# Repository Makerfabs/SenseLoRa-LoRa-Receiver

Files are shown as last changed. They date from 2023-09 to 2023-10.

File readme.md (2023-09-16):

# SENSELORA LORA RECEIVER

```c++
/*
Version:		V1.0
Author:			Vincent
Create Date:	2023/9/16
Note:

*/
```
# Makerfabs

[Makerfabs home page](https://www.makerfabs.com/)

[Makerfabs Wiki](https://wiki.makerfabs.com/)

# How To Use

## Arduino Complier Option

**If you have any questions，such as how to install the development board, how to download the code, how to install the library. Please refer to :[Makerfabs_FAQ](https://github.com/Makerfabs/Makerfabs_FAQ)**

- Please disconnect from the electrical equipment before burning!
- Do not burn with alternating current!
- Open Arduino IDE
- Open boards Manager, search "RP2040"
- Install board:  Arduino Mbed OS RP2040 Boards(Version 4.0.4)

Arduino libraries:

- RP2040_SD 1.0.1  
- RadioLib 4.6.0  
- Adafruit_GFX_Library 1.11.5  
- Adafruit_BusIO 1.14.1  
- Adafruit_SSD1306 2.5.1  

## Data Analysis

Once the device is plugged in, run data_analysis.py and the serial port will be found automatically. In addition, the json data uploaded by the device is classified according to ID and stored into different CSV files.

Make sure that no other serial device is connected, or modify the Python program yourself.

Environment:

- Python      3.11.2
- pyserial    3.5

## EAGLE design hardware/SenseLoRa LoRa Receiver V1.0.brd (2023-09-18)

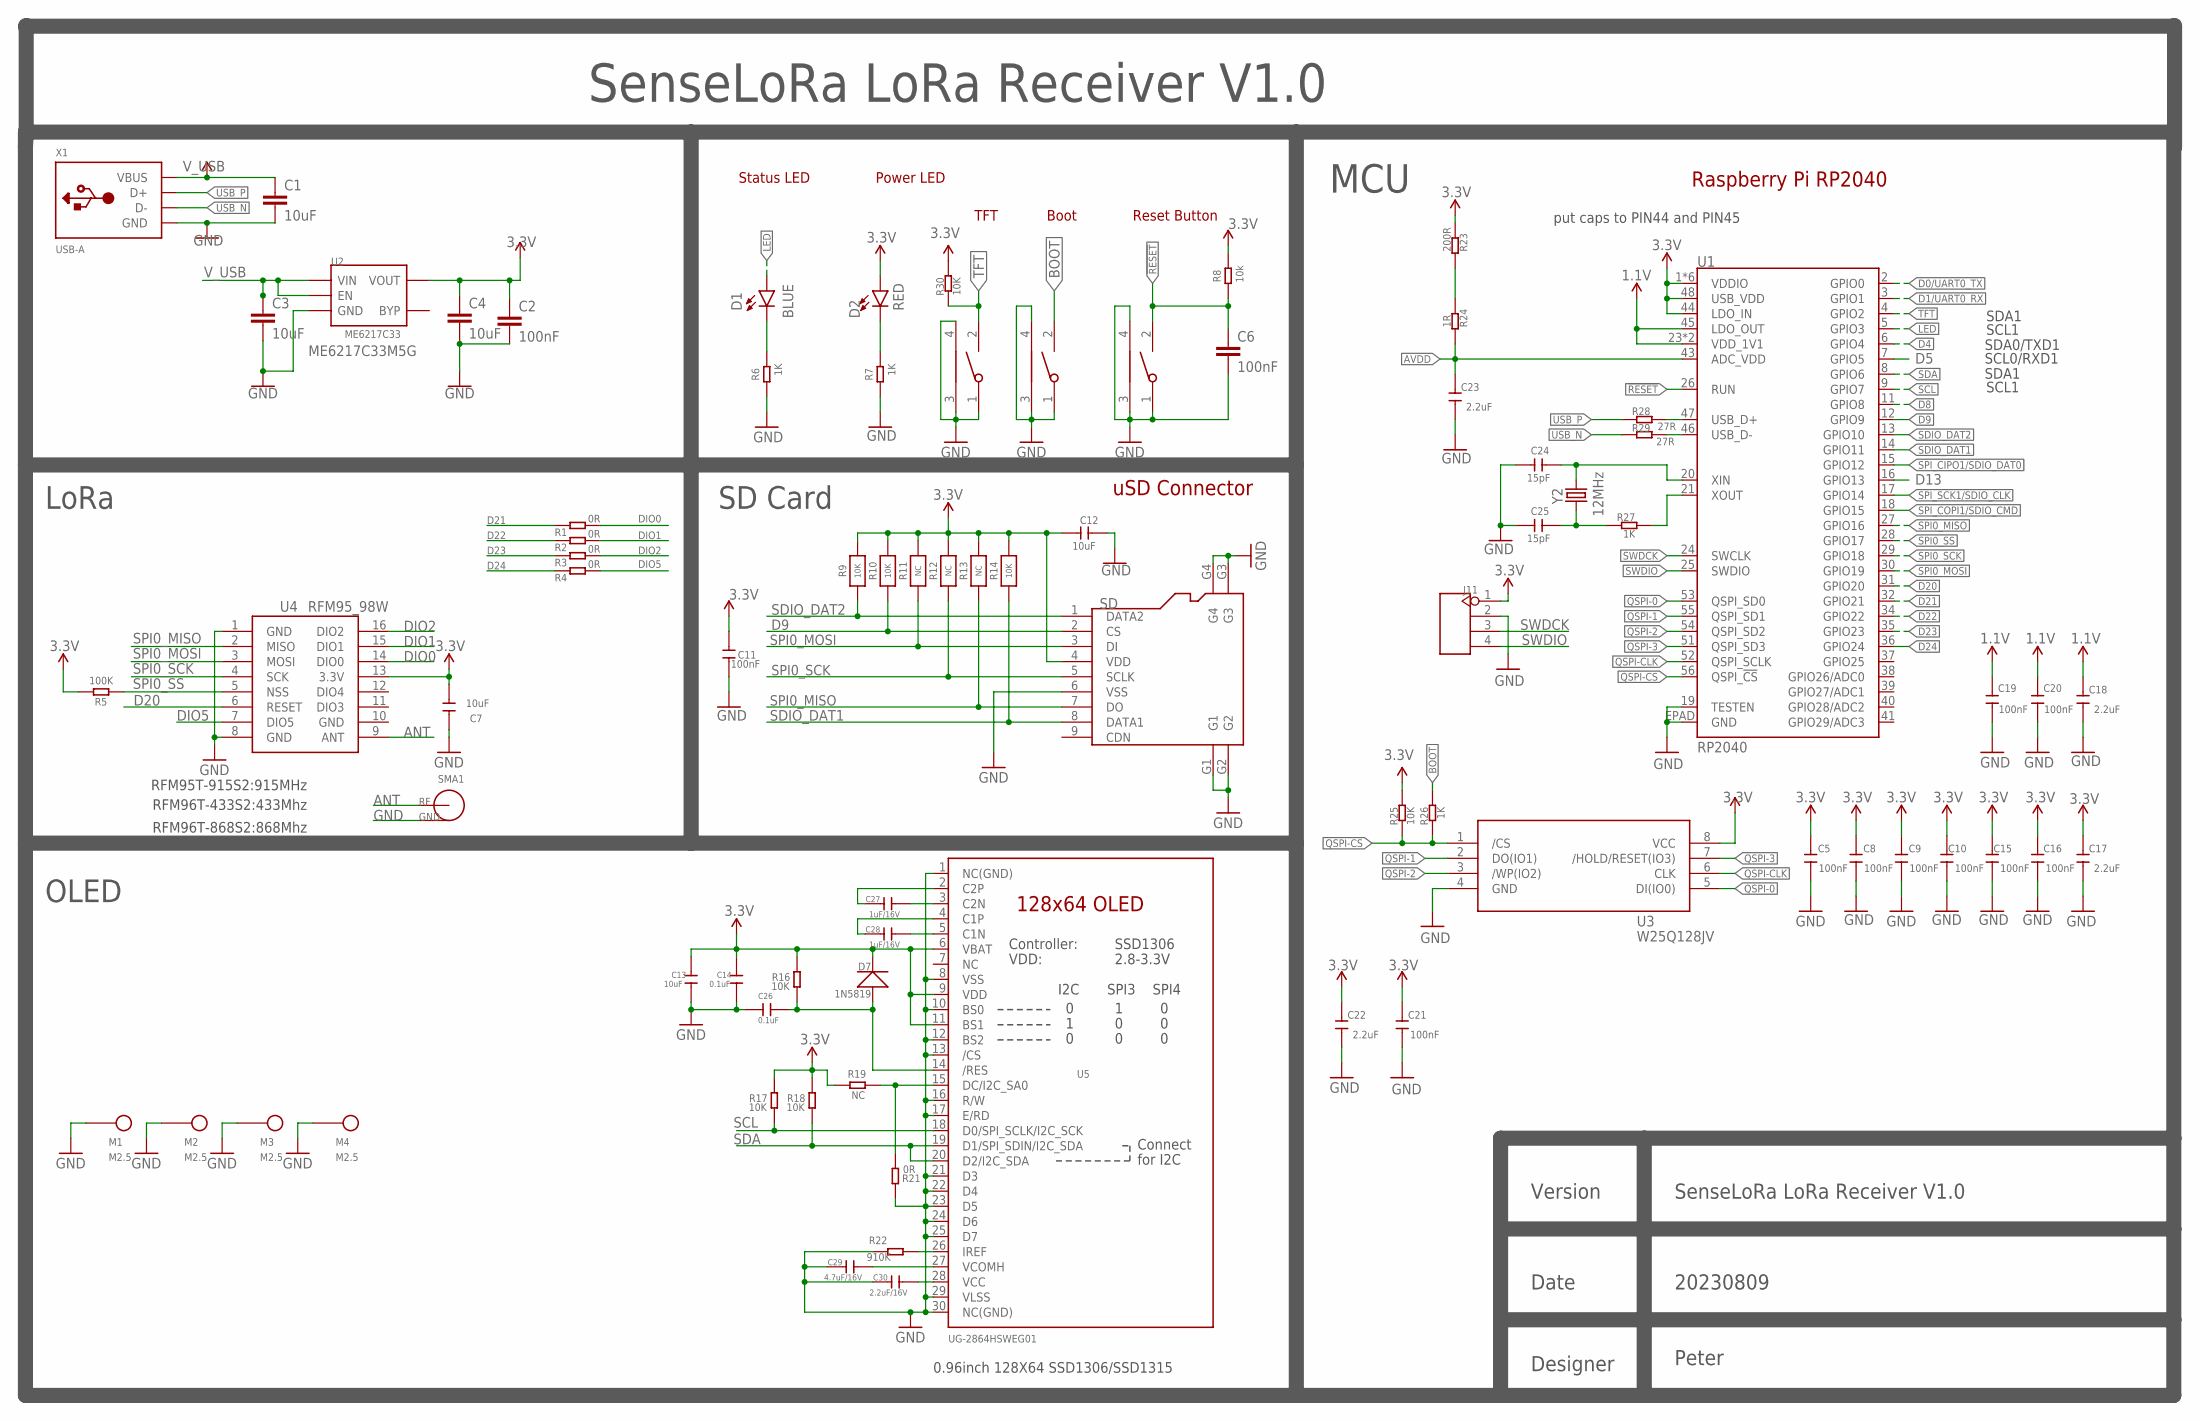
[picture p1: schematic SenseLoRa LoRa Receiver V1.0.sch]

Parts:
BOOT: TS24CA; 2*4*3.5MM
C1, C3, C4, C7, C13: 10uF; C0603
C2, C5, C6, C8, C9, C10, C11, C15, C16, C19, C20, C21: 100nF; C0603
C12: 10uF; DISCRETE_C0603
C14, C26: 0.1uF; C0603
C17, C18, C22, C23: 2.2uF; C0603
C24, C25: 15pF; C0603
C27, C28: 1uF/16V; C0603
C29: 4.7uF/16V; C0603
C30: 2.2uF/16V; C0603
D1: BLUE; LED-0603
D2: RED; LED-0603
D7: 1N5819; SOD323
J11: HEADER-4P-60/35MILROUND; 4P-65/35ROUND
M1, M2, M3, M4: M2.5
R1, R2, R3, R4, R21: 0R; 0603
R5: 100K; 0603
R6, R7, R26, R27: 1K; 0603
R8: 10k; 0603
R9, R10, R14: 10K; 0603-NO
R11, R12, R13: NC; 0603-NO
R16, R17, R18, R25, R30: 10K; 0603
R19: NC; 0603
R22: 910K; 0603
R23: 200R; 0603
R24: 1R; 0603
R28, R29: 27R; 0603
RST: TS24CA; 2*4*3.5MM
SD: HOLDER-MICROSD-9P; 9P-SMD-W/-RING
SMA1: SMA-KWE
TFT: TS24CA; 2*4*3.5MM
U1: RP2040; QFN-56
U2: ME6217C33; SOT23-5
U3: W25Q128JV; SOIC-8-208MIL
U4: RFM95_98W; RFM92_93W
U5: UG-2864HSWEG01; UG-2864HSWEG01_0.96IN_WRAPAROUND
X1: USB-A; MOLEX_480371000
Y2: 12MHz; CRYSTAL-SMD-2X2.5MM

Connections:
1.1V: C18.2, C19.2, C20.2, U1.23 (VDD_1V1), U1.45 (LDO_OUT), U1.50 (VDD_1V1)
3.3V: C2.1, C4.1, C5.2, C7.2, C8.2, C9.2, C10.2, C11.2, C12.2, C13.1, C14.1, C15.2, C16.2, C17.2, C21.2, C22.2, D2.A, D7.-, J11.1, R5.2, R8.1, R9.2, R10.2, R11.2, R12.2, R13.2, R14.2, R16.2, R17.2, R18.2, R19.2, R23.2, R25.1, R30.1, SD.4 (VDD), U1.1 (VDDIO), U1.10 (VDDIO), U1.22 (VDDIO), U1.33 (VDDIO), U1.42 (VDDIO), U1.44 (LDO_IN), U1.48 (USB_VDD), U1.49 (VDDIO), U2.5 (VOUT), U3.8 (VCC), U4.13 (3.3V), U5.6 (VBAT), U5.9 (VDD), U5.11 (BS1)
!RESET!: C6.1, R8.2, RST.2, U1.26 (RUN)
ADC_VREF: R23.1, R24.2
ANT: SMA1.1 (SIG), U4.9 (ANT)
AVDD: C23.2, R24.1, U1.43 (ADC_VDD)
BOOT: BOOT.2, R26.1
D0/UART0_TX: U1.2 (GPIO0)
D1/UART0_RX: U1.3 (GPIO1)
D4: U1.6 (GPIO4)
D5: U1.7 (GPIO5)
D8: U1.11 (GPIO8)
D9: R10.1, SD.2 (CS), U1.12 (GPIO9)
D13: U1.16 (GPIO13)
D20: U1.31 (GPIO20), U4.6 (RESET)
D21: R1.2, U1.32 (GPIO21)
D22: R2.2, U1.34 (GPIO22)
D23: R3.2, U1.35 (GPIO23)
D24: R4.2, U1.36 (GPIO24)
DIO0: R1.1, U4.14 (DIO0)
DIO1: R2.1, U4.15 (DIO1)
DIO2: R3.1, U4.16 (DIO2)
DIO5: R4.1, U4.7 (DIO5)
GND: BOOT.1, BOOT.3, BOOT.4, C1.2, C2.2, C3.2, C4.2, C5.1, C6.2, C7.1, C8.1, C9.1, C10.1, C11.1, C12.1, C13.2, C14.2, C15.1, C16.1, C17.1, C18.1, C19.1, C20.1, C21.1, C22.1, C23.1, C24.2, C25.2, C26.1, C29.1, C30.1, J11.2, M1.1, M2.1, M3.1, M4.1, R6.2, R7.2, R21.2, R22.2, RST.1, RST.3, RST.4, SD.6 (VSS), SD.G1, SD.G2, SD.G3, SD.G4, SMA1.2 (GND), SMA1.3 (GND), SMA1.4 (GND), SMA1.5 (GND), TFT.1, TFT.3, TFT.4, U1.19 (TESTEN), U1.EPAD (GND), U2.2 (GND), U3.4 (GND), U4.1 (GND), U4.8 (GND), U4.10 (GND), U5.1 (NC(GND)), U5.8 (VSS), U5.10 (BS0), U5.12 (BS2), U5.13 (/CS), U5.16 (R/W), U5.17 (E/RD), U5.21 (D3), U5.22 (D4), U5.23 (D5), U5.24 (D6), U5.25 (D7), U5.29 (VLSS), U5.30 (NC(GND)), X1.4 (GND)
LED: D1.A, U1.5 (GPIO3)
unnamed: C24.1, U1.20 (XIN), Y2.P3 (2)
unnamed: D1.C, R6.1
unnamed: R19.1, R21.1, U5.15 (DC/I2C_SA0)
unnamed: R27.1, U1.21 (XOUT)
unnamed: C29.2, U5.27 (VCOMH)
unnamed: C25.1, R27.2, Y2.P1 (1)
unnamed: D2.C, R7.1
unnamed: C30.2, U5.28 (VCC)
unnamed: R22.1, U5.26 (IREF)
unnamed: C27.2, U5.3 (C2N)
unnamed: C27.1, U5.2 (C2P)
unnamed: C28.1, U5.4 (C1P)
unnamed: C28.2, U5.5 (C1N)
unnamed: C26.2, D7.+, R16.1, U5.14 (/RES)
QSPI-0: U1.53 (QSPI_SD0), U3.5 (DI(IO0))
QSPI-1: U1.55 (QSPI_SD1), U3.2 (DO(IO1))
QSPI-2: U1.54 (QSPI_SD2), U3.3 (/WP(IO2))
QSPI-3: U1.51 (QSPI_SD3), U3.7 (/HOLD/RESET(IO3))
QSPI-CLK: U1.52 (QSPI_SCLK), U3.6 (CLK)
QSPI-CS: R25.2, R26.2, U1.56 (QSPI_!CS!), U3.1 (/CS)
SCL: R17.1, U1.9 (GPIO7), U5.18 (D0/SPI_SCLK/I2C_SCK)
SDA: R18.1, U1.8 (GPIO6), U5.19 (D1/SPI_SDIN/I2C_SDA), U5.20 (D2/I2C_SDA)
SDIO_DAT1: R14.1, SD.8 (DATA1), U1.14 (GPIO11)
SDIO_DAT2: R9.1, SD.1 (DATA2), U1.13 (GPIO10)
SPI0_MISO: R13.1, SD.7 (DO), U1.27 (GPIO16), U4.2 (MISO)
SPI0_MOSI: R11.1, SD.3 (DI), U1.30 (GPIO19), U4.3 (MOSI)
SPI0_SCK: R12.1, SD.5 (SCLK), U1.29 (GPIO18), U4.4 (SCK)
SPI0_SS: R5.1, U1.28 (GPIO17), U4.5 (NSS)
SPI_CIPO1/SDIO_DAT0: U1.15 (GPIO12)
SPI_COPI1/SDIO_CMD: U1.18 (GPIO15)
SPI_SCK1/SDIO_CLK: U1.17 (GPIO14)
SWDCK: J11.3, U1.24 (SWCLK)
SWDIO: J11.4, U1.25 (SWDIO)
TFT: R30.2, TFT.2, U1.4 (GPIO2)
USB_F_N: R29.1, U1.46 (USB_D-)
USB_F_P: R28.1, U1.47 (USB_D+)
USB_N: R29.2, X1.2 (D-)
USB_P: R28.2, X1.3 (D+)
V_USB: C1.1, C3.1, U2.1 (VIN), U2.3 (EN), X1.1 (VBUS)

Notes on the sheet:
RFM95T-915S2:915MHz
RFM96T-433S2:433Mhz
uSD Connector
Raspberry Pi RP2040
Reset Button
Status LED
Boot
Power LED
put caps to PIN44 and PIN45
SDA0/TXD1
SCL0/RXD1
SDA1
SCL1
RFM96T-868S2:868Mhz
LoRa
MCU
SenseLoRa LoRa Receiver V1.0
Version
Date
Designer
20230809
Peter
ME6217C33M5G
SD Card
0.96inch 128X64 SSD1306/SSD1315
OLED
TFT

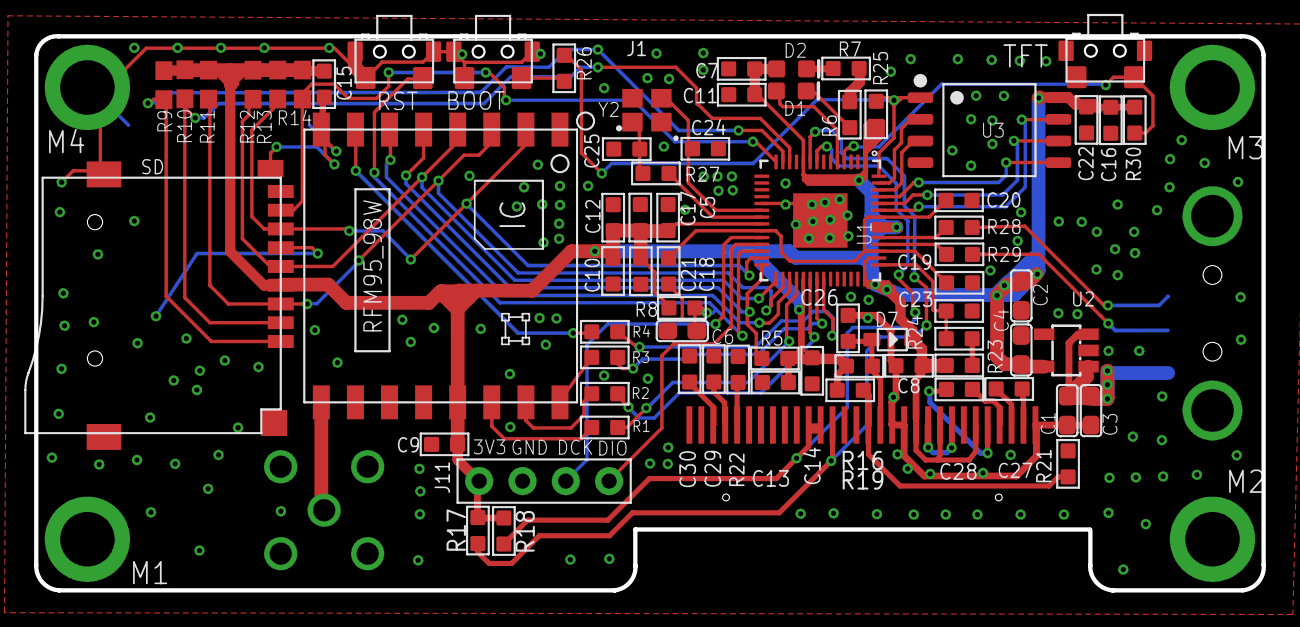
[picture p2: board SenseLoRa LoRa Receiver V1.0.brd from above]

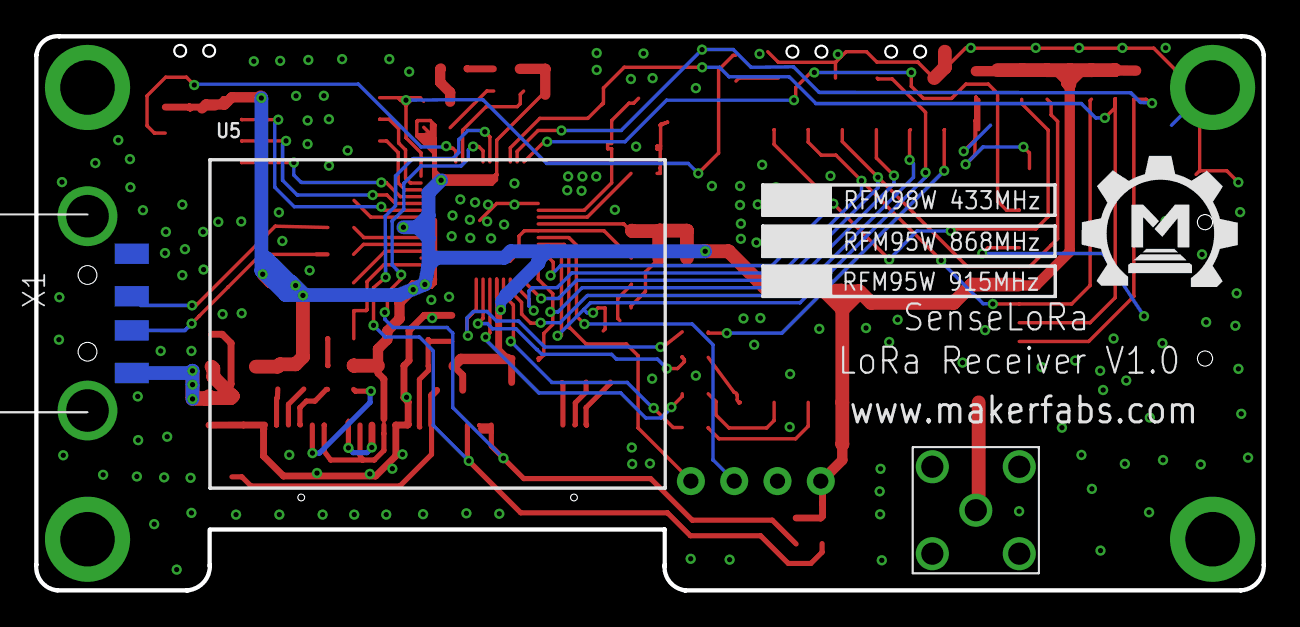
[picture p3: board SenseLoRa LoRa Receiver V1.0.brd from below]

Board: 2 copper layers, 72.0 x 32.5 mm, 79 parts (4 on the bottom side), 55 nets.

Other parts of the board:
U$1: MAKERFABS_0.3

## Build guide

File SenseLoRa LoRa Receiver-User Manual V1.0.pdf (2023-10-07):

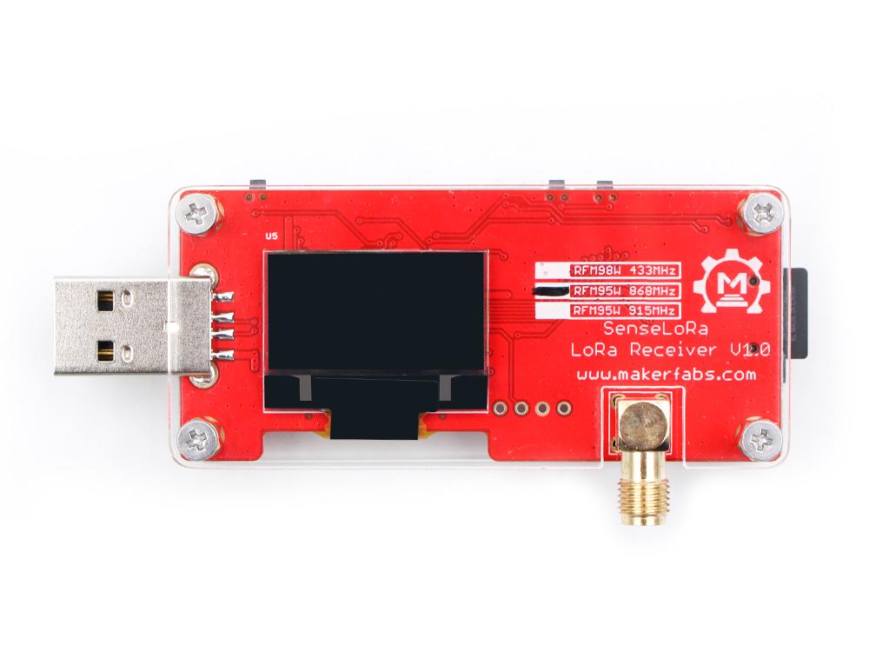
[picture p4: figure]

1 / 8

# SenseLoRa LoRa Receiver

### Version： V1.0

### Data： 2023-09-26

### Author： Peter

2 / 8

## Contents

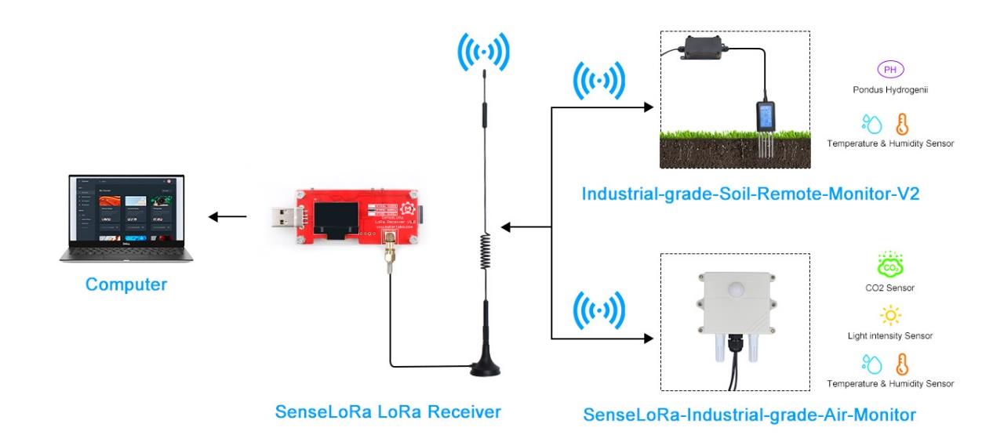
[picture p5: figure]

3 / 8

# 1. Introduction

### 1.1 Function

LoRa Receiver is a data receiver based on LoRa P2P protocol. It can receive

data sent by multiple sensor products around and forward to computer so the

data can be displayed/recorded and analysis via the PC.

LoRa Receiver is connected to the computer via USB. The received real-

time data can be displayed real time on the PC , and also on the screen of the

product, while the backup is saved to the SD card.

User can also view the sensor data received through the serial port of the

computer, and can also analyze the data saved in EXCEL.

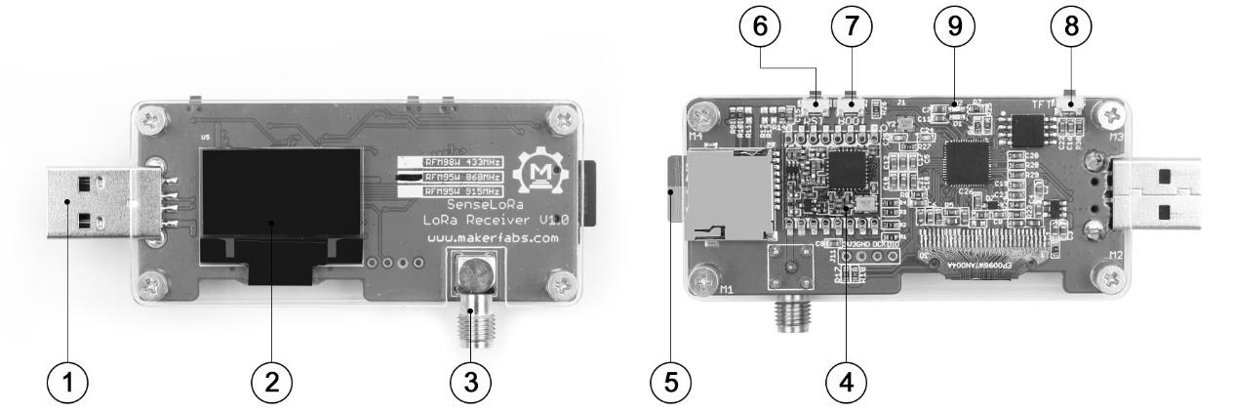
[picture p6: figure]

4 / 8

### 1.2 General description

① USB-A interface

② Display

③ Antenna

④ LoRa

⑤ SD card

⑥ Reset button

⑦ Burn button

⑧ Display rotation button

⑨ Power LED

# 2. Installation

### 2.1 Part List

Description | Specification | PCS
Receiver | 88mm*34mm*18mm | 1
Antenna | 5000mm | 1
Micro SD card | 16GB | 1

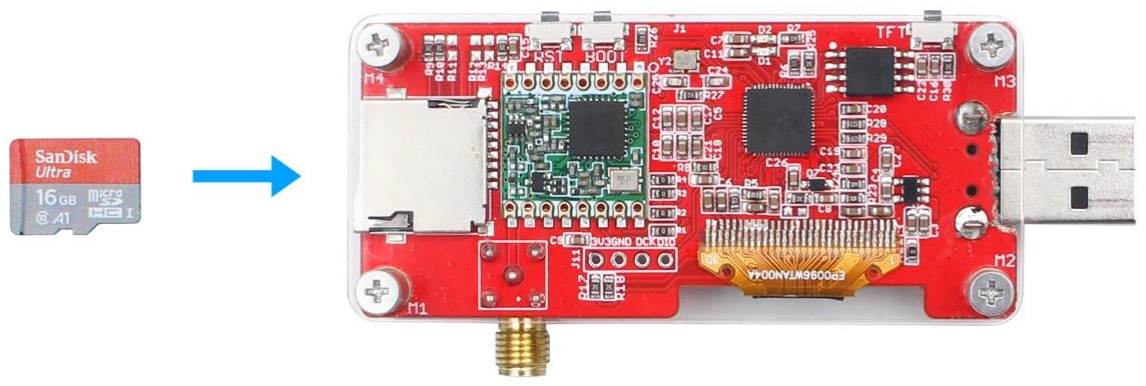
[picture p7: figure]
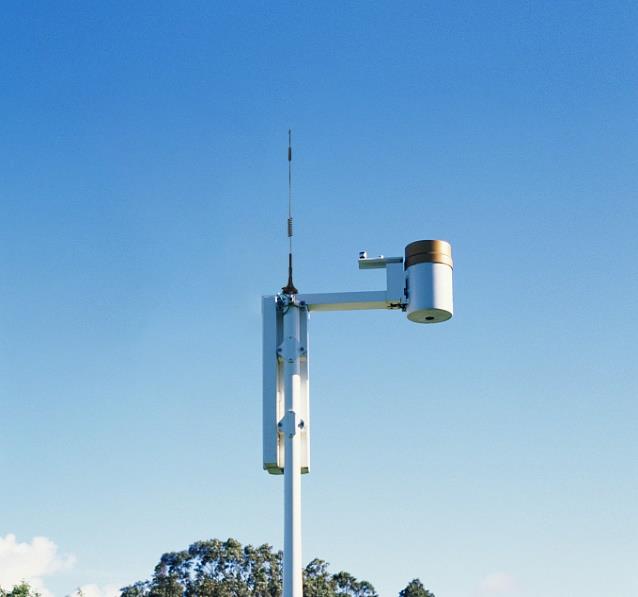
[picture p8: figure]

5 / 8

### 2.2 SD card Installation

Take out the SD card and place it in the SD card slot.

### 2.3 Antenna Installation

The antenna is 5m long, can be installed outside, to ensure the best LoRa

communication range.

Working with Makerfabs SenseLoRa nodes, the LoRa communication arrange

can be up to 4~5 KM.

### 2.4 Power Supply

The product connects to the computer via USB to work.

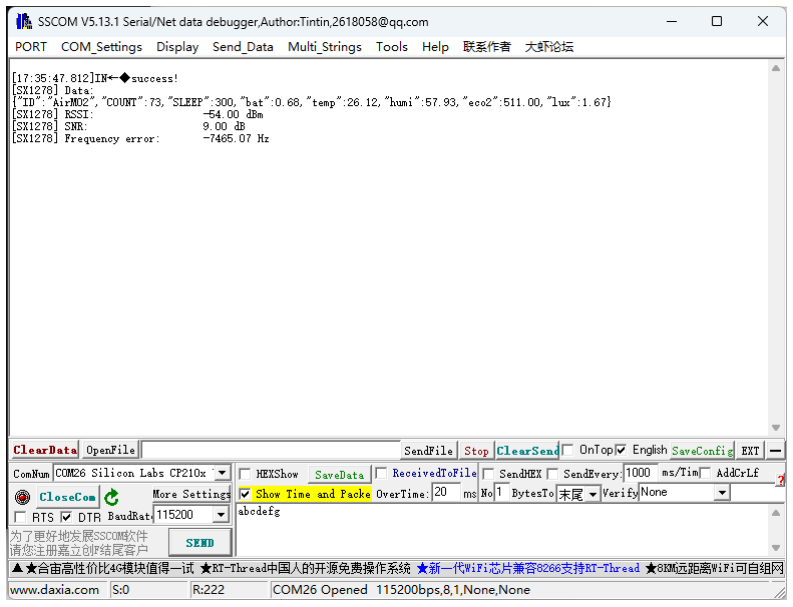
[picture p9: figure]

6 / 8

## 3. Data Management

The product is installed and receives sensor data. Users can save and

process data in several ways.

### 3.1 Serial port

Open the serial port tool on the PC, the parameters are set as follows：

Baud rate : 115200

Data bits : 8

Stop bits : 1

Parity :None

Flow control : None

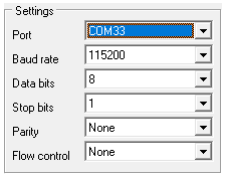
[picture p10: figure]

Select the product port and open it, the received sensor data will be

displayed in real time.

### 3.2 Python Application

The URL: https://github.com/Makerfabs/SenseLoRa-LoRa-Receiver/tree/main/data_analysis

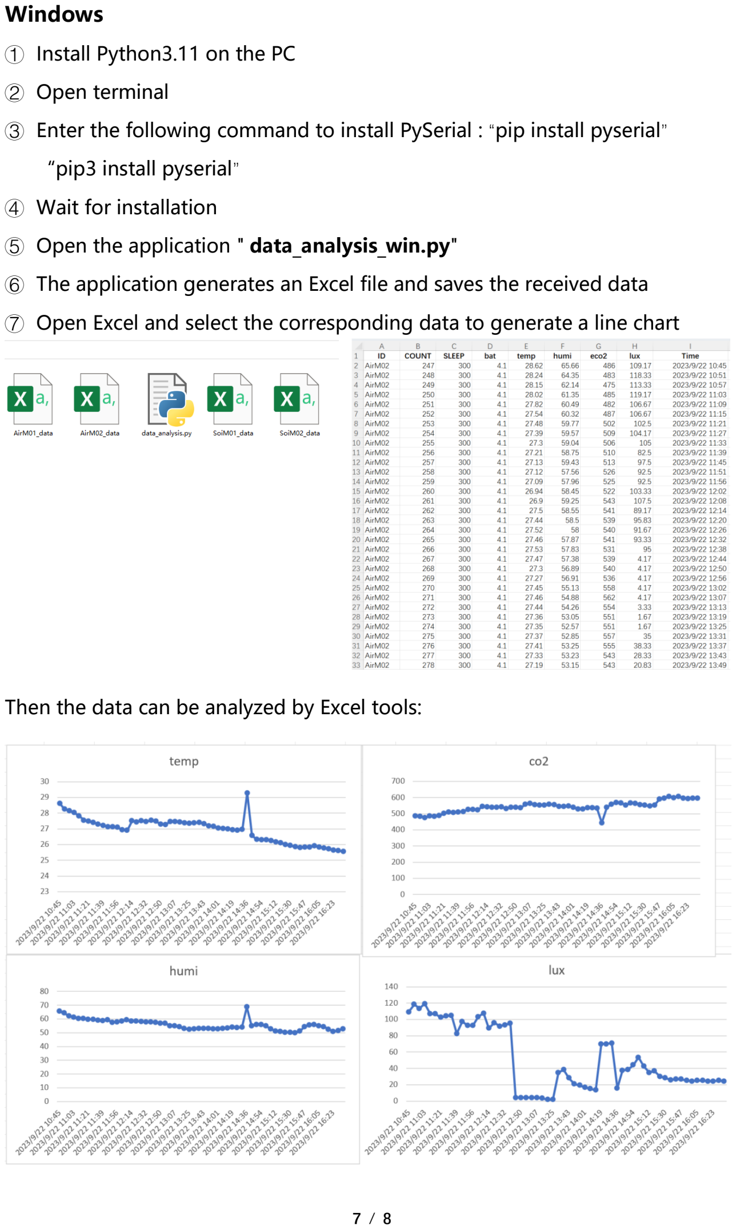
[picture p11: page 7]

7 / 8

### Windows

① Install Python3.11 on the PC

② Open terminal

③ Enter the following command to install PySerial : “pip install pyserial”

“pip3 install pyserial”

④ Wait for installation

⑤ Open the application " data_analysis_win.py"

⑥ The application generates an Excel file and saves the received data

⑦ Open Excel and select the corresponding data to generate a line chart

Then the data can be analyzed by Excel tools:

8 / 8

### Mac OS x

① Install Python3.11 on the PC

② Open terminal

③ Enter the following command to install PIP : “python -m ensurepip”

④ Enter the following command to install PySerial : “pip install pyserial” or

“pip3 install pyserial”

⑤ Wait for installation

⑥ Open the application " data_analysis_mac.py"

⑦ The application generates an Excel file and saves the received data

⑧ Data analysis as above

### 3.3 SD card

All LoRa data are also been stored in the SD card, can be a back up for

long time monitoring in application.

## 4. Specifications

Model | SenseLoRa LoRa Receiver
Power supply | 5V / 0.5W
Frequency Bands | EU868/ US915
Physical characteristics
Dimensions (height x width x Depth) | 88 x 34 x 18mm
Weight main unit | 65g
Antenna length | 5000mm

Operating conditions

Temperature -40°C to +80°C

Relative humidity 15% to 90% (no condensation) Storage conditions

Temperature -20°C to +50°C

Relative humidity 15% to 90% (no condensation)

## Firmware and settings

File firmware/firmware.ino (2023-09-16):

/*

Must change pins_arduino.h
File may in this place:
C:\Users\vincent\AppData\Local\Arduino15\packages\arduino\hardware\mbed_rp2040\4.0.4\variants\RASPBERRY_PI_PICO\pins_arduino.h

// Wire
// #define PIN_WIRE_SDA        (4u)
// #define PIN_WIRE_SCL        (5u)

// Change By Vincent
#define PIN_WIRE_SDA        (6u)
#define PIN_WIRE_SCL        (7u)

*/

// Arduino Mbed OS RP2040 Boards version 4.0.4
// 使用库 SPI 在文件夹： C:\Users\vincent\AppData\Local\Arduino15\packages\arduino\hardware\mbed_rp2040\4.0.4\libraries\SPI (legacy)
// 使用 1.0.1  版本的库 RP2040_SD 在文件夹： C:\Users\vincent\Documents\Arduino\libraries\RP2040_SD
// 使用 4.6.0  版本的库 RadioLib 在文件夹： C:\Users\vincent\Documents\Arduino\libraries\RadioLib
// 使用库 Wire 在文件夹： C:\Users\vincent\AppData\Local\Arduino15\packages\arduino\hardware\mbed_rp2040\4.0.4\libraries\Wire (legacy)
// 使用 1.11.5  版本的库 Adafruit_GFX_Library 在文件夹： C:\Users\vincent\Documents\Arduino\libraries\Adafruit_GFX_Library
// 使用 1.14.1  版本的库 Adafruit_BusIO 在文件夹： C:\Users\vincent\Documents\Arduino\libraries\Adafruit_BusIO
// 使用 2.5.1  版本的库 Adafruit_SSD1306 在文件夹： C:\Users\vincent\Documents\Arduino\libraries\Adafruit_SSD1306

#include "config.h"

Adafruit_SSD1306 display(SCREEN_WIDTH, SCREEN_HEIGHT, &Wire, -1);
SX1276 radio = new Module(LORA_CS, LORA_DIO0, LORA_RST, LORA_DIO1, SPI, SPISettings());
File root;
File myFile;
long unsigned int runtime = 0;
int count = 0;
int sd_flag = 0;
int screen_rotation = 2;
int button_flag = 0;

int last_rssi = 0;
String oled_str = "No Massage";
int flesh_flag = 0;

void setup(void)
{
    Serial.begin(115200);

    pinMode(LORA_CS, OUTPUT);
    pinMode(SD_CS, OUTPUT);

    pinMode(PIN_SPI_MISO, INPUT);
    pinMode(PIN_SPI_MOSI, OUTPUT);
    pinMode(PIN_SPI_SCK, OUTPUT);

    pinMode(BUTTON_PIN, INPUT_PULLUP);

    delay(2000);
    Serial.println(F("Hello! SenseLoRa LoRa Receiver"));

    oled_init();
    sd_flag = sd_init();
    lora_init();

    while (0)
    {
        lora_send_task("AAAA");
        delay(10000);
    }

    runtime = millis();
    attachInterrupt(BUTTON_PIN, button_func, FALLING); // CHANGE FALLING RISING
    flesh_flag = 1;
}

void loop()
{
    if (button_flag == 1)
    {
        if (screen_rotation == 2)
            screen_rotation = 0;
        else
            screen_rotation = 2;
        display.setRotation(screen_rotation);
        Serial.println("Rotation OLED");
        button_flag = 0;

        flesh_flag = 1;
    }

    if (flesh_flag == 1)
    {
        oled_display();
        flesh_flag = 0;
    }

    lora_node_general();
    if ((millis() - runtime) > 5000)
    {
        // record_msg("loop");
        // log_read();
        runtime = millis();
    }
}

void lora_init()
{
    SD_CS_OFF;
    LORA_CS_ON;

    int state = radio.begin(FREQUENCY, BANDWIDTH, SPREADING_FACTOR, CODING_RATE, SX127X_SYNC_WORD, OUTPUT_POWER, PREAMBLE_LEN, GAIN);

    if (state == ERR_NONE)
    {
        Serial.println(F("Lora init success!"));
    }
    else
    {
        Serial.print(F("Lora init failed, code "));
        Serial.println(state);
        while (true)
            ;
    }
}

void lora_node_general()
{
    // Serial.print(F("[SX1278] Waiting for incoming transmission ... "));

    String str;
    int state = radio.receive(str);

    if (state == ERR_NONE)
    {
        int rssi = radio.getRSSI();
        // // packet was successfully received
        // Serial.println(F("Get lora message!"));

        // // print the data of the packet
        // Serial.println(F("[SX1278] Data:\t\t\t"));
        Serial.println(str);

        // // print the RSSI (Received Signal Strength Indicator)
        // // of the last received packet
        // Serial.print(F("[SX1278] RSSI:\t\t\t"));
        // Serial.print(rssi);
        // Serial.println(F(" dBm"));

        // // print the SNR (Signal-to-Noise Ratio)
        // // of the last received packet
        // Serial.print(F("[SX1278] SNR:\t\t\t"));
        // Serial.print(radio.getSNR());
        // Serial.println(F(" dB"));

        // // print frequency error
        // // of the last received packet
        // Serial.print(F("[SX1278] Frequency error:\t"));
        // Serial.print(radio.getFrequencyError());
        // Serial.println(F(" Hz"));

        String temp = "";
        temp = temp + "Num:" + ++count;
        record_msg(temp);
        record_msg(str);

        oled_str = str;
        last_rssi = rssi;
        flesh_flag = 1;
    }
    else if (state == ERR_RX_TIMEOUT)
    {
        // timeout occurred while waiting for a packet
        // Serial.println(F("timeout!"));
    }
    else if (state == ERR_CRC_MISMATCH)
    {
        // packet was received, but is malformed
        Serial.println(F("CRC error!"));
    }
    else
    {
        // some other error occurred
        Serial.print(F("failed, code "));
        Serial.println(state);
    }
}

int sd_init()
{
    LORA_CS_OFF;
    SD_CS_ON;

    int fail_count = 0;

    while (1)
    {
        if (fail_count > 2)
            return 0;
        if (!SD.begin(SD_CS))
        {
            SD.end();
            Serial.println("SD init failed!");
            fail_count++;
            delay(500);
            continue;
        }
        else
        {
            Serial.println("SD init done.");
            record_msg("New Restart.......");
            return 1;
        }
    }
}

void record_msg(String data)
{
    if (!sd_flag)
        return;
    LORA_CS_OFF;
    SD_CS_ON;

    File myFile = SD.open(LOG_FILE, FILE_WRITE);

    myFile.println(data.c_str());
    myFile.close();

    SD_CS_OFF;
    LORA_CS_ON;
}

void log_read()
{
    if (!sd_flag)
        return;
    LORA_CS_OFF;
    SD_CS_ON;

    Serial.println("log_read()");

    File myFile = SD.open(LOG_FILE, FILE_READ);
    while (myFile.available())
    {
        Serial.write(myFile.read());
    }

    // close the file:
    myFile.close();

    SD_CS_OFF;
    LORA_CS_ON;
}

void oled_init()
{
    Wire.begin();
    Wire.setClock(100000UL);

    if (!display.begin(SSD1306_SWITCHCAPVCC, 0x3C))
    { // Address 0x3C for 128x32
        Serial.println(F("SSD1306 allocation failed"));
        for (;;)
            ; // Don't proceed, loop forever
    }
    Serial.println("SSD1306 found");

    display.setRotation(screen_rotation);
    display.clearDisplay();
    for (int16_t x = 0; x < display.width(); x += 1) // SCREEN_WIDTH
    {
        for (int16_t y = 0; y < display.height(); y += 1) //
        {
            display.drawPixel(x, y, SSD1306_WHITE);
        }
        delay(1);
    }
    display.display();

    delay(2000);

    display.clearDisplay();
    display.setTextColor(SSD1306_WHITE);
    display.setTextSize(2); // Draw 2X-scale text
    display.setCursor(0, 0);
    display.println("SenseLoRa");
    display.println("LoRa");
    display.println("Receiver");
    display.display();

    display.setTextSize(1);
}

void button_func()
{
    button_flag = 1;
}

//

void lora_send_task(String data)
{
    Serial.println(data);
    int state = radio.transmit(data.c_str());
    if (state == ERR_NONE)
    {
        // the packet was successfully transmitted
        Serial.println(F(" success!"));

        // print measured data rate
        Serial.print(F("[SX1276] Datarate:\t"));
        Serial.print(radio.getDataRate());
        Serial.println(F(" bps"));
    }
    else if (state == ERR_PACKET_TOO_LONG)
    {
        // the supplied packet was longer than 256 bytes
        Serial.println(F("too long!"));
    }
    else if (state == ERR_TX_TIMEOUT)
    {
        // timeout occurred while transmitting packet
        Serial.println(F("timeout!"));
    }
    else
    {
        // some other error occurred
        Serial.print(F("failed, code "));
        Serial.println(state);
    }
}

void oled_display()
{
    String temp = "";
    temp = temp + "Num:" + count;

    display.clearDisplay();
    display.setCursor(0, 0);
    display.print(temp);
    display.println((String) " | " + last_rssi + "dbm");
    display.println(oled_str);
    display.display();
}

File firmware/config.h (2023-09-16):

#include <SPI.h>
#include <RP2040_SD.h>
#include <RadioLib.h>
#include <Wire.h>
#include <Adafruit_GFX.h>
#include <Adafruit_SSD1306.h>
#include <arduino.h>

// Pin

#define BUTTON_PIN 2

#define I2C_SDA_PIN 6
#define I2C_SCL_PIN 7

#define PIN_SPI_MISO (16u)
#define PIN_SPI_MOSI (19u)
#define PIN_SPI_SCK (18u)
#define PIN_SPI_SS (17u)

#define LORA_DIO0 21
#define LORA_DIO1 22
#define LORA_DIO2 23
#define LORA_DIO5 24
#define LORA_RST 20

#define LORA_CS 17
#define SD_CS 9

#define LORA_CS_OFF digitalWrite(LORA_CS, HIGH)
#define LORA_CS_ON digitalWrite(LORA_CS, LOW)
#define SD_CS_OFF digitalWrite(SD_CS, HIGH)
#define SD_CS_ON digitalWrite(SD_CS, LOW)

// Oled
#define SCREEN_WIDTH 128 // OLED display width, in pixels
#define SCREEN_HEIGHT 64 // OLED display height, in pixels

// Lora
#define FREQUENCY 868.0
#define BANDWIDTH 125.0
#define SPREADING_FACTOR 12
#define CODING_RATE 6
#define OUTPUT_POWER 20
#define PREAMBLE_LEN 8
#define GAIN 0

// SD
#define LOG_FILE "Lora_Log.txt"

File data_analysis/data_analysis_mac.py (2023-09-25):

# coding=utf-8
import serial
import time
import json
import csv
import os
import serial.tools.list_ports


def main():

    time.sleep(5)
    ser.write("begin".encode('UTF-8'))

    while True:
        read_data()
    pass


# Get lora message!
# [SX1278] Data:			
# {"ID":"0xAAAA","SLEEP":10,"temp":0.00,"humi":0.00,"eco2":0.00,"lux":0.00}
# [SX1278] RSSI:			-55 dBm
# [SX1278] SNR:			9.75 dB
# [SX1278] Frequency error:	4744.54 Hz
# Get lora message!
# [SX1278] Data:			
# {"ID":"0xBBBB","SLEEP":10,"temp":0.00,"humi":0.00,"eco2":0.00,"lux":0.00}
# [SX1278] RSSI:			-41 dBm
# [SX1278] SNR:			9.50 dB
# [SX1278] Frequency error:	767.82 Hz
# Get lora message!
# [SX1278] Data:			
# {"ID":"0xAAAA","SLEEP":10,"temp":0.00,"humi":0.00,"eco2":0.00,"lux":0.00}
# [SX1278] RSSI:			-54 dBm
# [SX1278] SNR:			9.50 dB
# [SX1278] Frequency error:	4744.02 Hz


def read_data():

    ser.reset_input_buffer()
    line = ser.readline().decode('UTF-8').replace('\n', '')
    # line = ser.readline().decode('UTF-8')
    # print(line)

    try:
        data = json.loads(line)
        list_title = []
        list_value = []
        print(data)
        for key in data:
            # print(key, data[key])
            list_title.append(key)
            list_value.append(data[key])

        time_str = time.strftime("%Y-%m-%d %H:%M:%S ",
                                 time.localtime(time.time()))
        print(time_str)
        print(list_title)
        print(list_value)

        list_value.append(time_str)
        list_title.append("Time")

        if list_title[0] == "ID":
            save_data(list_title, list_value)

    except:
        print("LOG:", line)


def save_data(list_title, list_value):
    filename = str(list_value[0]) + "_data.csv"
    title_flag = 0

    # 判断文件是否存在
    if os.path.exists(filename):
        print('Old sensor')

    else:
        print('New sensor')
        title_flag = 1

    file = open(filename, mode='a', newline='')
    writer = csv.writer(file)
    if title_flag == 1:
        writer.writerow(list_title)
    writer.writerow(list_value)

    file.close()


def get_com_list():
    global port_list
    port_list = serial.tools.list_ports.comports()
    return port_list


def get_frist_com():
    if len(get_com_list()) <= 0:
        print("No COM")
        return ""
    else:
        print("First COM")
        port_list = get_com_list()
        for com in port_list:
            print(com)
            for i in com:
                print(i)
                if i == "RaspberryPi Pico":
                    return list(com)[0]
            
        return NULL

# print("Input Serial number, don't add COM, just number.")
# serial_num = input()
# serial_num = "COM" + str(serial_num)
# ser = serial.Serial(serial_num, 115200)


ser = serial.Serial(get_frist_com(), 115200)

if __name__ == '__main__':
    main()

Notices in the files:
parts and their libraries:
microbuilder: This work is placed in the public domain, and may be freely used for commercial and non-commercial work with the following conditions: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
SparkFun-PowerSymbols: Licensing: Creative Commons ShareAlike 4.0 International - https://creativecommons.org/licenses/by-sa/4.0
